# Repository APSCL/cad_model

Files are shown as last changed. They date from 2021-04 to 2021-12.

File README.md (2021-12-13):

# cad_model
CAD Models for 3D Printing

Note: Autodesk Inventor was used to model. You can get a free license with your .edu email.

## Design
### Revision 3
Revision 2 required tight tolerances, which made manufacturing and adjusting hard. Revision 3 solves this issue by relying on nuts and bolts instead of friction based pins. This revision also reduces plate size for faster prints and easier access to ports and wires. It also features the new mount for the Raspberry Pi instead of the Jetson Nano. The holes are sized for M2.5 screws. This should also make the structure stronger and easier to work on.

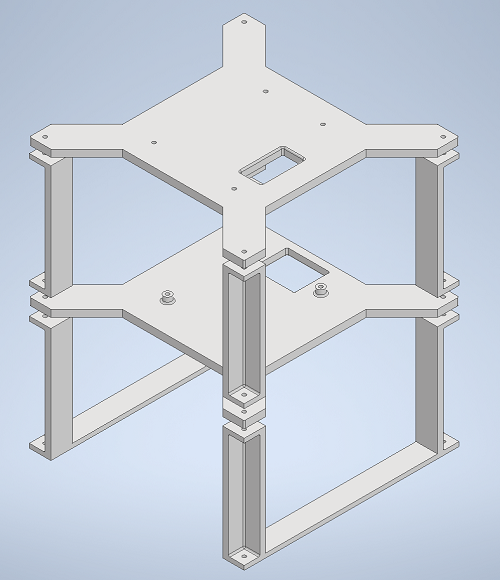
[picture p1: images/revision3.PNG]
Revision 2 Image
 

### Revision 2
Revision 1 faced numerous manufacturing challenges at TIW including print time and print quality. Revision 2 intends to solve these issues by making the parts more modular, standardized, and printable. This revision uses a 13 cm x 13 cm mounting hole design, allowing for universal compatibility of different parts created. The hole diameter is 0.55 cm while the connecting pins have a diameter of 0.45 cm.

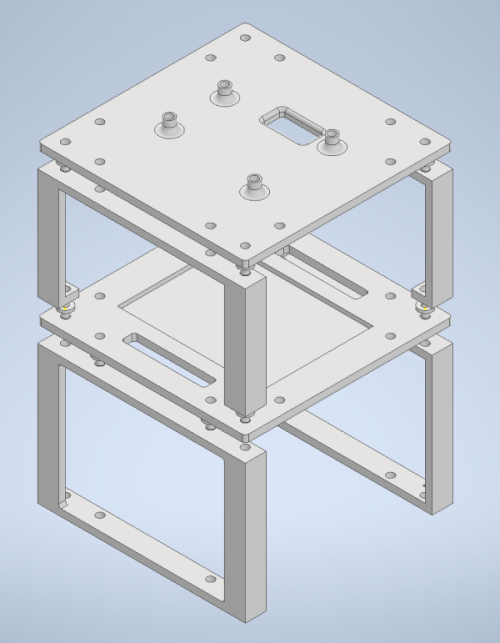
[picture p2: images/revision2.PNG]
Revision 2 Image
 

### Revision 1
Revision 1 featured complete tables per stage. LIDAR mount was modular via a square cutout.

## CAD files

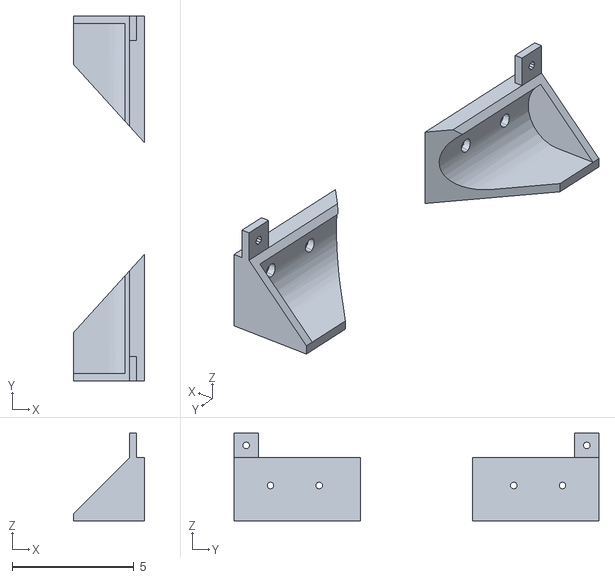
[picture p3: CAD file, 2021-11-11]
Revision 3/usb_battery_pocket_2.stl
2.90 x 15.0 x 3.60

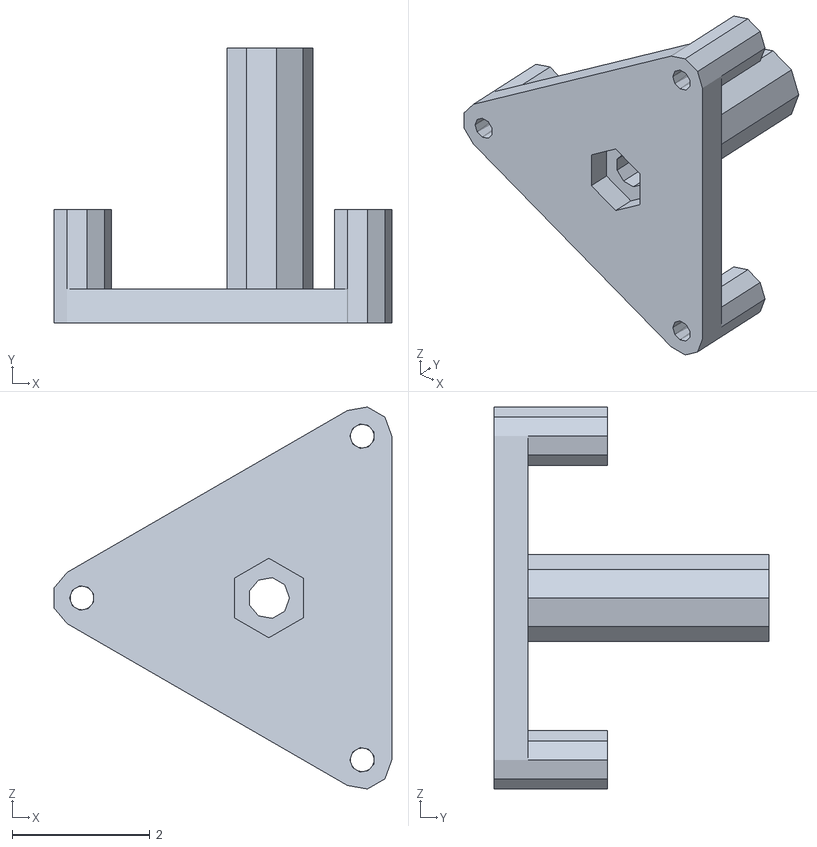
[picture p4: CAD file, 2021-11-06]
Revision 3/wheel_block.stl
4.90 x 4.00 x 5.55

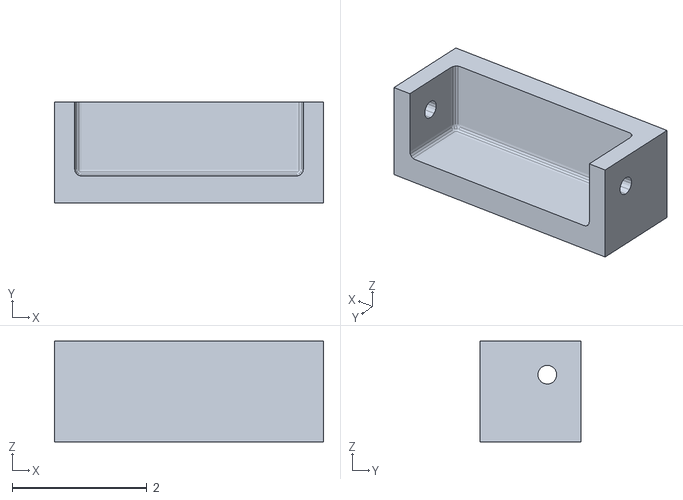
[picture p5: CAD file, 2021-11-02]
Revision 3/leg_4.stl
4.00 x 1.50 x 1.50

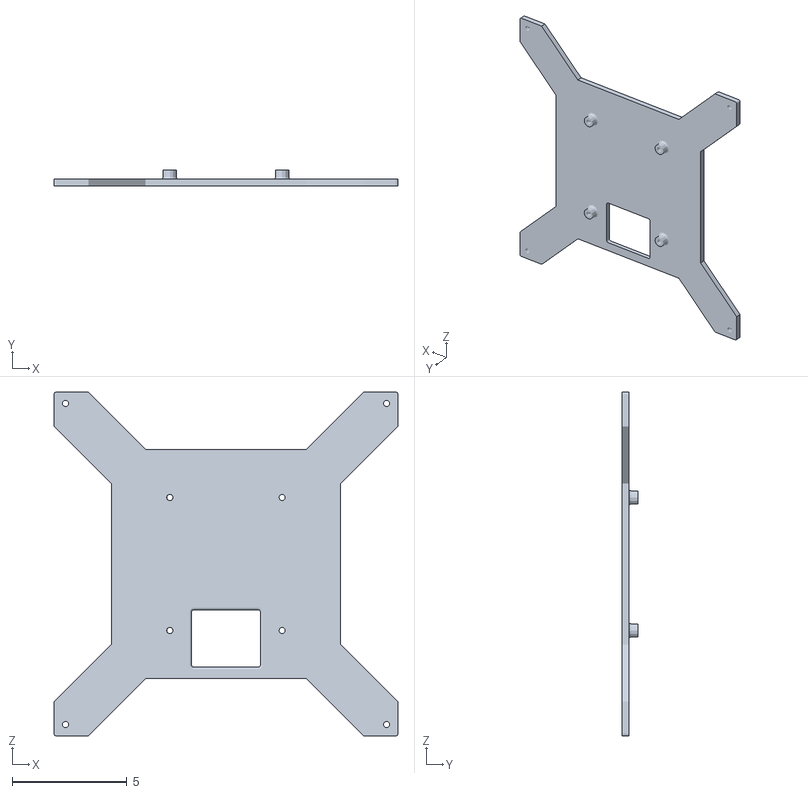
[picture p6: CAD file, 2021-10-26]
Revision 3/pi_base.stl
15.0 x 0.7 x 15.0

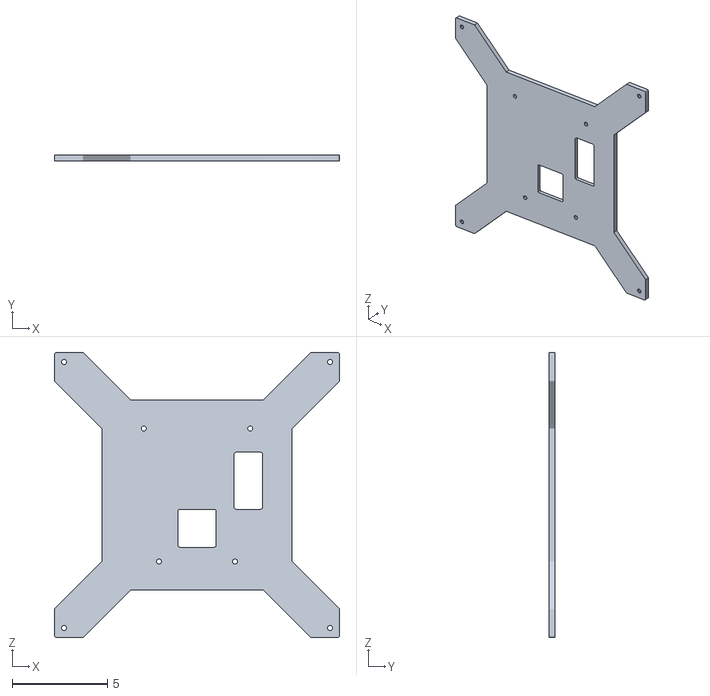
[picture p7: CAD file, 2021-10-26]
Revision 3/lidar_base.stl
15.0 x 0.3 x 15.0

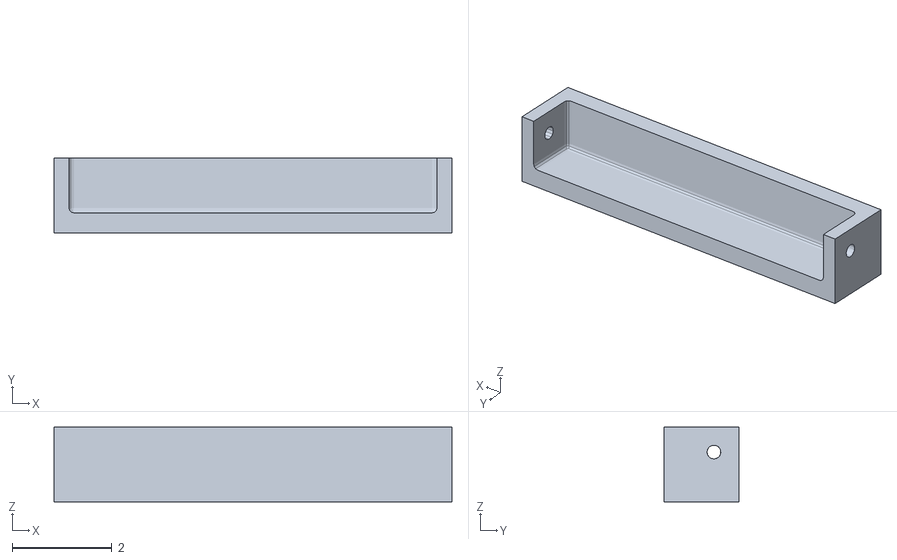
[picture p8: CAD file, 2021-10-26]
Revision 3/leg_8.stl
8.00 x 1.50 x 1.50

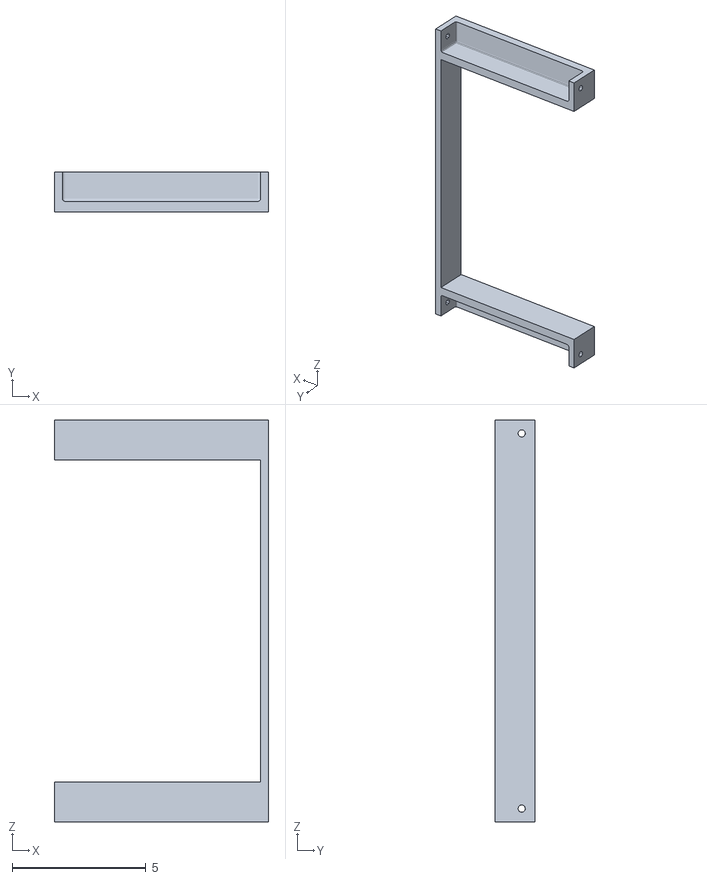
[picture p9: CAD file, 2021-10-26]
Revision 3/leg_8u.stl
8.00 x 1.50 x 15.0

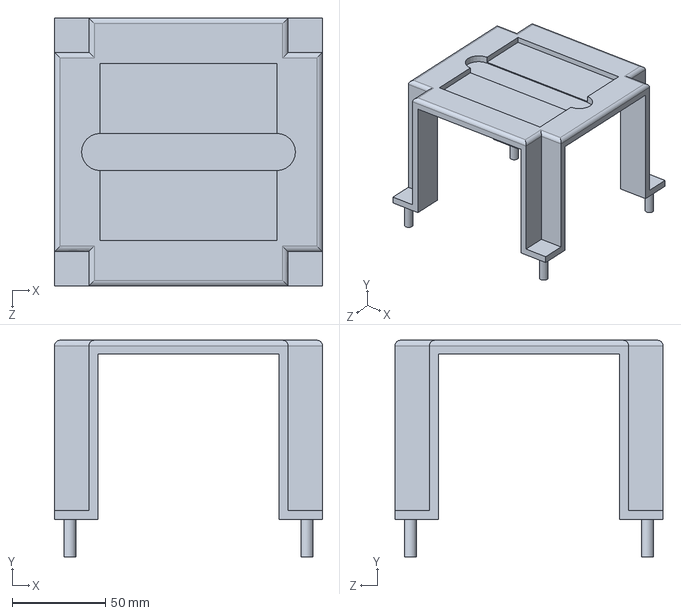
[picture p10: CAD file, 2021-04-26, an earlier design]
Revision 1/new_Lidar_Table.SLDPRT
144.0 x 116.4 x 144.0 mm

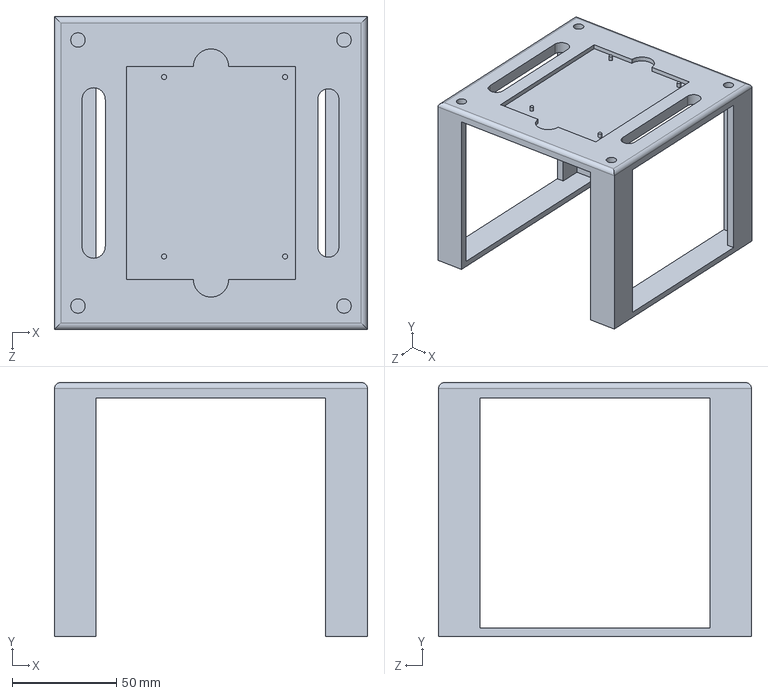
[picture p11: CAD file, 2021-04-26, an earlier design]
Revision 1/new_JetsonNano_table.SLDPRT
150.0 x 121.8 x 150.0 mm

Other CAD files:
Revision 1/new_JetsonNano_table.STL
Revision 1/new_Lidar_Table.STL
Revision 3/Part1.ipt
Revision 3/leg_4.ipt
Revision 3/leg_8.ipt
Revision 3/leg_8u.ipt
Revision 3/lidar_base.ipt
Revision 3/pi_base.ipt
Revision 3/usb_battery_pocket_2.ipt
Revision 3/wheel_block.ipt

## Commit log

2021-04-23 Add Rev. 2 Lidar Base
    [lidar_base.ipt, lidar_base.stl, lidar_base.stp]
2021-04-23 Reduce height for screw compatibility
    [lidar_base.ipt, lidar_base.stl, lidar_base.stp]
2021-10-21 Rev 3 Structure
    [leg_8.ipt, leg_8u.ipt, lidar_base.ipt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]
2021-10-21 Change to 14x14mm mounting
    [leg_8.ipt, leg_8u.ipt, lidar_base.ipt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]
2021-10-26 Change hole size > 2.8mm. Add STL
    [leg_8.ipt, leg_8.stl, leg_8u.ipt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]
2021-10-30 Add battery pocket & pins
    [hot_pin_6.ipt, hot_pin_6.stl, usb_battery_pocket.ipt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]
2021-10-31 Revise battery pocket
    [usb_battery_pocket.ipt, usb_battery_pocket.stl, usb_battery_pocket_2.ipt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]
2021-11-02 Add leg_4
    [leg_4.ipt, leg_4.stl]
2021-11-06 Add wheel_block, remove hot_pin
    [hot_pin_6.ipt, hot_pin_6.stl, wheel_block.ipt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]
2021-11-08 Revise wheel hubs for tolerance
    [wheel_block.ipt, wheel_block.stl]
2021-11-08 Revert "Revise wheel hubs for tolerance"
    This reverts commit b5e009fd8de29ec72a135464386f1252159a5afc.
    [wheel_block.ipt, wheel_block.stl]
2021-11-09 reduce hole size 6.5>6.3
    [wheel_block.ipt]
2021-11-11 update battery pocket for tolerance
    [usb_battery_pocket_2.ipt, usb_battery_pocket_2.stl]
